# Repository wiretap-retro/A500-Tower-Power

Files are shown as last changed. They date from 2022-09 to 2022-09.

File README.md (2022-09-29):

# A500 Tower Power
A small ATX to Amiga 500 power adapter for towerized A500 builds. Includes 3 fan connectors.

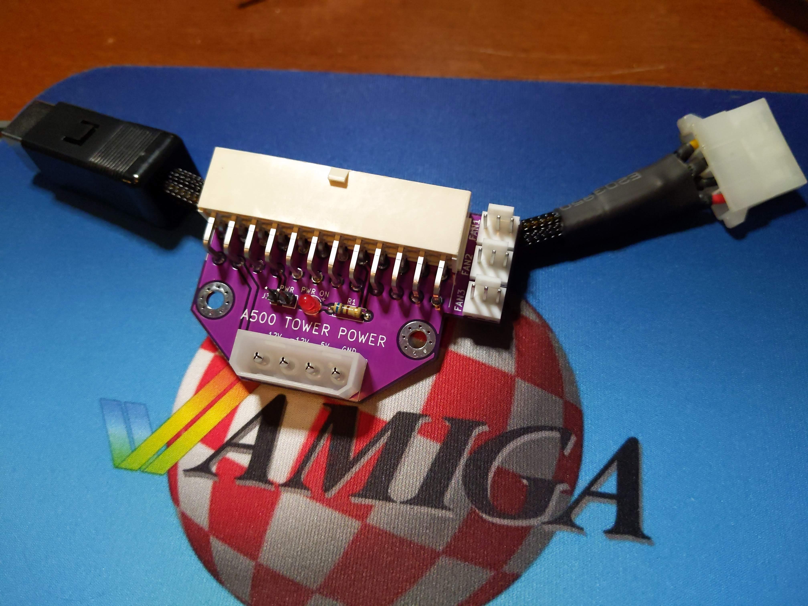
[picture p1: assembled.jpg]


## Intro
I developed this adapter for my Amiga 500 tower project. It mounts to the motherboard tray or any other convenient area inside the case via two standoffs. It allows you to plug in a standard ATX power supply and provides a 4-pin molex connector (for the A500 power connector) along with 3 standard fan headers for 12V fans. 

## Assembly / Installation
* Order the PCB from your fabricator of choice. (JLCPCB, PCBway, OSH Park, etc.) This is a 4-layer PCB, so JLCPCB will probably be cheapest.
* Order the parts per the BOM. Mouser part numbers are included. A standard 2-pin 2.54mm pin header, 3mm LED, and a standard resistor are also needed, but who doesn't have those laying around?
* Solder the J3 pin header, LED, and resistor first. Alternatively, you can put another 2x2.54mm pin header in place of the LED to use it as a front panel power LED.
* Solder the 4-pin molex, 24-pin ATX header, and the 3-pin fan headers.
* Obtain an A500 power connector either from a failed power supply or order a new connector.
* From an old ATX power supply, molex passthrough, or molex splitter, clip the leads of a 4-pin molex so you have only the female end with long leads.
* Strip and tin the leads of the 4-pin molex cable and solder them into the Amiga 500 power connector, paying close attention to pinouts of both the A500 and this power adapter board. (heatshrink the wires if necessary at this step)
* Plug the A500 to 4-pin molex dongle into the A500 Tower Power adapter.
* Mount the power adapter in a conventient location in your case, then plug in all the power connectors. The 2-pin PWR switch is for a standard toggle switch (or latching push button) for controlling the ATX power supply on/off function. I recommend swapping out the ATX case power button with a latching push button if you can find one that works for you. Alternatively, you can place a jumper on these pins and utilize the switch on the rear of the ATX power supply for on/off control.
* Power on the Amiga Tower and enjoy.

## Revision Info
* Rev 1: Moved power LED from PG over to the 5V line. The PG signal turns off after the ATX power supply tests itself, depending on the PSU. Important if you wanted to use it as a power LED on the front of the case by putting a 2-pin header there instead.
* Rev 0: Initial rev -- tested/working

## Misc
This is an open source design. Feel free to do what you want with it.

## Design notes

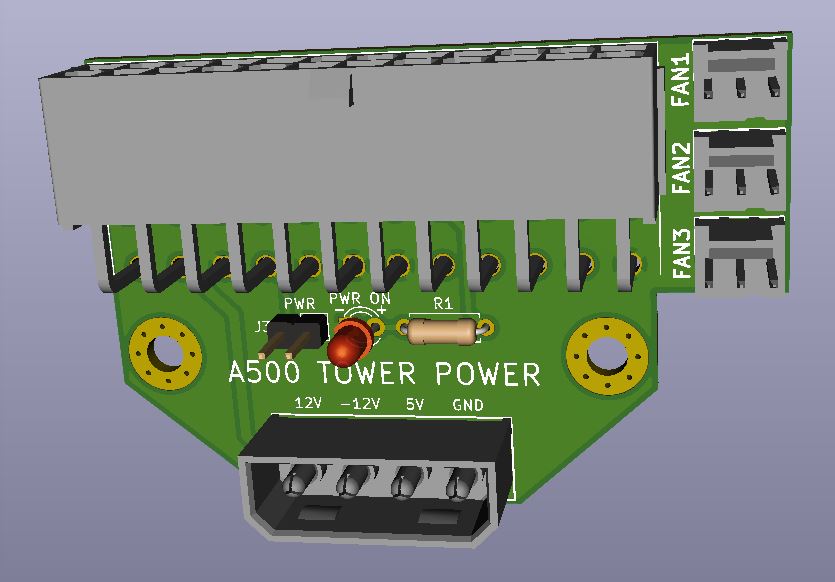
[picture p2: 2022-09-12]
pic.jpg

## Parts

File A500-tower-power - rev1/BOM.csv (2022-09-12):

Reference | Value | Footprint | Description | Manufacturer_Name | Manufacturer_Part_Number | Mouser Part Number
D1 | LED_3mm | LED_THT:LED_D3.0mm
J1 | 87427-2402 | 87427-2402 | Mini-Fit Jr. Header, 4.20mm Pitch, Right-Angle, without Flange, 24 Circuits, Tin (Sn) over Nickel (Ni) Plating Series: 87427 | Molex | 87427-2402 | 538-87427-2402
J2 | 15-24-4449 | SHDR4W166P0X508_1X4_2326X828X1066P | MOLEX - 15-24-4449 - HEADER, ICAL MOUNT, 4WAY | Molex | 15-24-4449 | 538-15-24-4449
J3 | Conn_01x02 | Connector_PinHeader_2.54mm:PinHeader_1x02_P2.54mm_Vertical
J4 | 22-23-2031 | SHDR3W82P0X254_1X3_747X635X818P | 2.54mm,header,KK,vert,Sn,frictn lock,3w Molex KK 254 Series, Series Number 6373, 2.54mm Pitch 3 Way 1 Row Straight PCB Header, Through Hole, Solder Termination | Molex | 22-23-2031 | 538-22-23-2031
J5 | 22-23-2031 | SHDR3W82P0X254_1X3_747X635X818P | 2.54mm,header,KK,vert,Sn,frictn lock,3w Molex KK 254 Series, Series Number 6373, 2.54mm Pitch 3 Way 1 Row Straight PCB Header, Through Hole, Solder Termination | Molex | 22-23-2031 | 538-22-23-2031
J6 | 22-23-2031 | SHDR3W82P0X254_1X3_747X635X818P | 2.54mm,header,KK,vert,Sn,frictn lock,3w Molex KK 254 Series, Series Number 6373, 2.54mm Pitch 3 Way 1 Row Straight PCB Header, Through Hole, Solder Termination | Molex | 22-23-2031 | 538-22-23-2031
R1 | 1k | Resistor_THT:R_Axial_DIN0207_L6.3mm_D2.5mm_P7.62mm_Horizontal

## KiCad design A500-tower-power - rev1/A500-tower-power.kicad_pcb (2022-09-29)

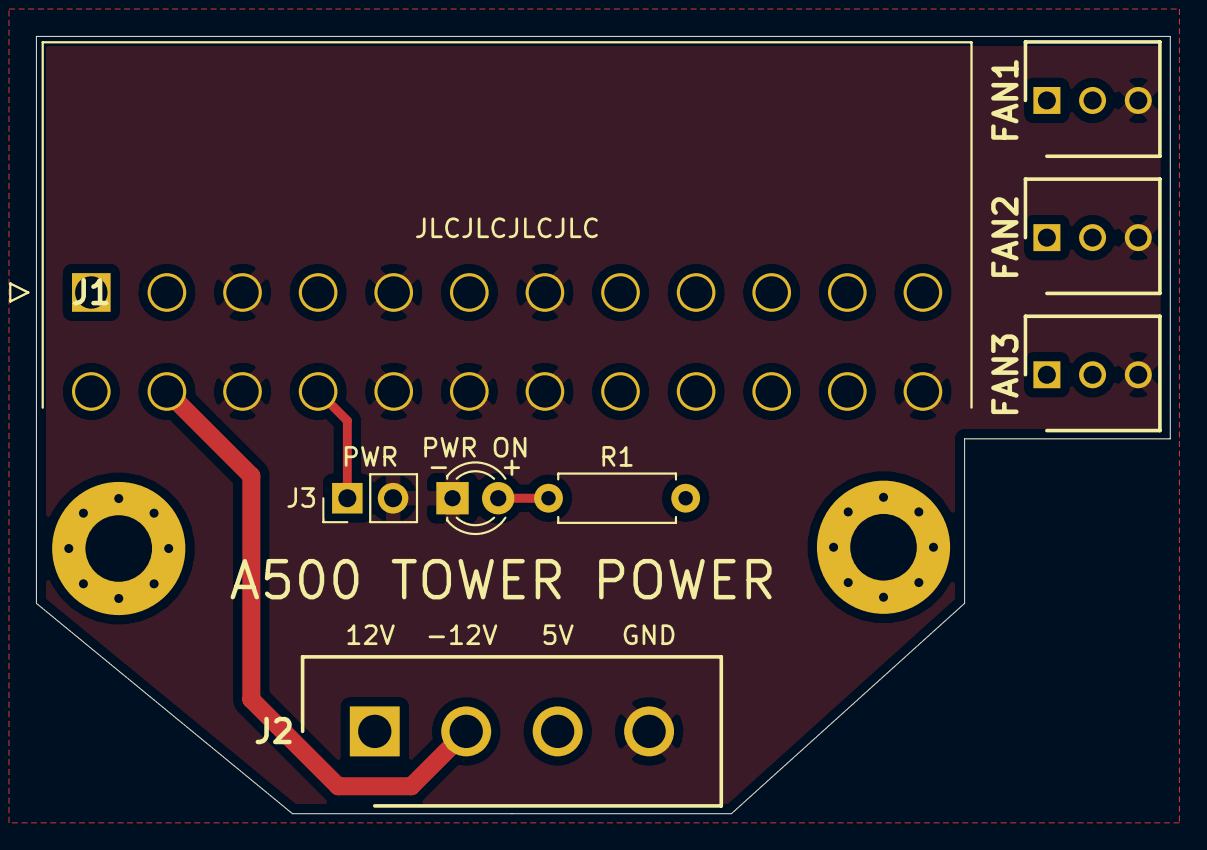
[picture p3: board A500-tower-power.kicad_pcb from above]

Board: 4 copper layers, 63.0 x 43.2 mm, 10 parts (0 on the bottom side), 7 nets.

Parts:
D1: LED_3mm; LED_D3.0mm
FAN1, FAN2, FAN3: 22-23-2031; SHDR3W82P0X254_1X3_747X635X818P
H1, H2: MountingHole; MountingHole_3.7mm_Pad_Via
J1: 87427-2402
J2: 15-24-4449; SHDR4W166P0X508_1X4_2326X828X1066P
J3: Conn_01x02; PinHeader_1x02_P2.54mm_Vertical
R1: 1k; R_Axial_DIN0207_L6.3mm_D2.5mm_P7.62mm_Horizontal

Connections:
/3.3V: J1.1, J1.2, J1.12, J1.13
/5V: J1.4, J1.6, J1.21, J1.22, J1.23, J2.3, R1.2
/12V: FAN1.2, FAN2.2, FAN3.2, J1.10, J1.11, J2.1
/-12V: J1.14, J2.2
/GND: D1.1, FAN1.3, FAN2.3, FAN3.3, J1.3, J1.5, J1.7, J1.15, J1.17, J1.18, J1.19, J1.24, J2.4, J3.2
/PS-ON: J1.16, J3.1
unnamed: D1.2, R1.1
